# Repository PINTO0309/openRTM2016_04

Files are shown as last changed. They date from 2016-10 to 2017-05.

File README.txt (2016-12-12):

README

甲南大学知能情報学部
2016/10/31
2016/12/10 アップデートにあわせて改訂
2016/12/12 作例：ライントレーサーのアップデート，利用マニュアルの改訂，Zumo通信プロトコル解説マニュアルの追加

このフォルダには，RTミドルウェアコンテスト2016に参加している「ZumoとRaspberry Piを用いた教育用ロボット環境」の作品データが保存されています．作品は以下のフォルダ，ファイルから構成されています．

(1) Zumo ロボット用 RT Component群
　　(a) 基本コンポーネント
    (b) ゲームパッド入力コンポーネント
    (c) ゲームパッド速度指令コンポーネント
    (d) Zumo-Raspberry Pi間通信テスト用コンポーネント群
    (e) 作例：ライントレーサー
(2) Zumo ロボット内制御プログラム (Micro USBポート接続版(通常はこちらを使用), GPIO接続版(Raspberry Pi A+用)）
(3) Zumo基板上にRaspberry Piを搭載するためのCADデータ
(4) Zumoロボットの利用マニュアル

(2)のロボット内制御プログラムは，Zumoロボット基板上のMicro USBポート経由でのシリアル通信（通常はこちらを使用）と，Zumoロボット基板上のGPIOシリアル通信を利用の場合（Raspberry Pi A+を想定）の2種類があります．通常はMicro USBポート経由のプログラムを用いますが，ご使用の環境に応じて，プログラムを使い分ける必要があります．

フォルダ，ファイルの一覧は以下のとおりです．

- README.txt		README
- ZumoComponents	Pololu Zumo 32U4 RTコンポーネント群
			- 基本コンポーネント
			- ゲームパッド入力
			- ゲームパッド速度指令コンポーネント
 +- IO_test		Zumo - Rasperry Pi 間の通信テスト用コンポーネント群
 +- sample		作例：ライントレーサー
- Zumo-USB		Zumoロボット内制御プログラム（Micro USBポート経由シリアル通信版，通常はこちらを使用）
- Zumo-GPIO		Zumoロボット内制御プログラム (GPIOシリアル通信版）
- CADData		ZumoロボットへのRaspberry Pi マイクロコントローラ搭載用CADデータ
- Manual.pdf		利用マニュアル
- ZumoCommunicationProtocol_Manual.pdf  Zumo通信プロトコル解説マニュアルの追加
これらの，フォルダ，ファイルを利用して，Zumoロボットのアプリケーションソフトウェアの開発が行えます．

以上

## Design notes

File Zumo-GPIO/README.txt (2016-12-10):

README

甲南大学知能情報学部
2016/10/31
2016/12/10  改訂 ソフトウェアの使用に関する注意（シリアル通信を行うための主な手段の変更による）

このフォルダには，RTミドルウェアコンテスト2016に参加している「ZumoとRaspberry Piを用いた教育用ロボット環境」のZumo ロボット内制御プログラム (GPIOシリアル通信版）が保存されています．作品は以下のファイルから構成されています．

(1) Zumo ロボット用 Arduino統合環境設定ファイル 
(2) ロボット制御用C++ソース，ヘッダファイル群

（注）
このロボット内制御プログラムは，Zumoロボット基板上のGPIOシリアル通信を利用の場合（Raspberry Pi A+を想定）用です．
Zumoロボット内制御プログラムには，Zumoロボット基板上のGPIOシリアル通信を利用の場合（Raspberry Pi A+を想定），Micro USBポート経由でのシリアル通信（通常はこちらを使用）の2種類があります．ご使用の環境に応じて，プログラムを使い分ける必要があります．

フォルダ，ファイルの一覧は以下のとおりです．

- README.txt		README
- Zumo-rasp.ino		Pololu Zumo 32U4用プログラム Arduino統合環境 設定ファイル
			（Zumoロボット基板上のGPIOシリアル通信を利用）
- *.cpp, *.h		モータ，ボタン，シリアル通信用プログラム

これらの，フォルダ，ファイルを利用して，Zumoロボットのアプリケーションソフトウェアの開発が行えます．Zumoロボットそのもの機能の追加には，このプログラム群を修正，改良して，開発を行います．

以上

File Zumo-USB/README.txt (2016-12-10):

README

甲南大学知能情報学部
2016/10/31
2016/12/10  改訂 ソフトウェアの使用に関する注意（シリアル通信を行うための主な手段の変更による）

このフォルダには，RTミドルウェアコンテスト2016に参加している「ZumoとRaspberry Piを用いた教育用ロボット環境」のZumo ロボット内制御プログラム （Micro USBポート経由でのシリアル通信版，通常はこちらを使用）が保存されています．作品は以下のファイルから構成されています．

(1) Zumo ロボット用 Arduino統合環境設定ファイル 
(2) ロボット制御用C++ソース，ヘッダファイル群

（注）
このロボット内制御プログラムは，Micro USBポート経由でのシリアル通信用です．通常はこちらのファイル群を使用します．
Zumoロボット内制御プログラムには，Micro USBポート経由でのシリアル通信（通常はこちらを使用），Zumoロボット基板上のGPIOシリアル通信を利用の場合（Raspberry Pi A+を想定）の2種類があります．ご使用の環境に応じて，プログラムを使い分ける必要があります．

フォルダ，ファイルの一覧は以下のとおりです．

- README.txt		README
- Zumo-rasp.ino		Pololu Zumo 32U4用プログラム Arduino統合環境 設定ファイル
			（Zumoロボット基板上のGPIOシリアル通信を利用）
- *.cpp, *.h		モータ，ボタン，シリアル通信用プログラム

これらの，フォルダ，ファイルを利用して，Zumoロボットのアプリケーションソフトウェアの開発が行えます．Zumoロボットそのもの機能の追加には，このプログラム群を修正，改良して，開発を行います．

以上

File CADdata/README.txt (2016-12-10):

README

甲南大学知能情報学部
2016/10/28
2016/12/10 改訂 治具の変更，追加に伴う改訂

このフォルダには，Zumoの基板上にRaspberry Piシリーズを載せるための治具のCADデータおよび3Dプリンタ(Afinia H480)用データ（STL形式）が保存されています．治具は以下の3種類のパーツから構成されています．

(1) 治具A
(2) 治具B
(3) スペーサー

これらのパーツのCADデータはDesignSparkにて作成しました．そのデータを治具についてはSTL形式，スペーサーについてはUP3形式に変換してあります．これらのデータが以下のファイル名で保存されています．

- JigA-1.stl, JigA-2.stl, JigA-3.stl, JigA-4.stl        治具A（Raspberry Pi Bシリーズ用）の3Dプリンタ用データ(STL形式)
- JigB-1.stl, JigB-2.stl       				治具B (Raspberry Pi A+用）3Dプリンタ用データ(STL形式)
- six_spacers.UP3  スペーサー6個分の3Dプリンタ用データ

これらの治具を用いてRaspberry Piコントローラを固定する方法については，本プロジェクトのマニュアルを参照してください．

以上

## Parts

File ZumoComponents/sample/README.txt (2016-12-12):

README

甲南大学知能情報学部
2016/10/31 作成
2016/12/10 ライントレーサー用RTコンポーネント改良
2016/12/12 ライントレーサー用RTコンポーネント改良,スイッチ駆動によるライントレーサー実行環境の追加

このフォルダには，RTミドルウェアコンテスト2016に参加している「ZumoとRaspberry Piを用いた教育用ロボット環境」のPololu Zumoロボット用RTコンポーネント群の作例が保存されています．

このフォルダには，本ロボットを動作させる作例として以下のファイル，フォルダから構成されています．

(1) 作例：ライントレーサーRTコンポーネント

これらのコンポーネントはPythonで書かれており，Raspberry Pi，Windows などプラットフォームを問わず，実行できます．これらのデータは以下のファイル名で保存されています．

- LineTracer.py		ライントレーサー用RTコンポーネント
+ SwitchExecute		スイッチ駆動によるライントレーサー実行環境のディレクトリ

これらのRTコンポーネント群を用いてZumoロボットのサンプルを動かす方法については，本プロジェクトのマニュアルを参照してください．

以上

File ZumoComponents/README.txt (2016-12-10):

README

甲南大学知能情報学部
2016/10/31
2016/12/10 Zumo制御用RTコンポーネント，作例（ライントレーサー用RTコンポーネント）改良

このフォルダには，RTミドルウェアコンテスト2016に参加している「ZumoとRaspberry Piを用いた教育用ロボット環境」のPololu Zumoロボット用RTコンポーネントが保存されています．

このフォルダには，本ロボットを動作させる最小構成のコンポーネント群として以下のファイル，フォルダから構成されています．

(1) Zumo制御用RTコンポーネント
(2) 速度指令RTコンポーネント
(3) ジョイスティック入力コンポーネント
(4) Zumoロボット 制御I/Oテスト用コンポーネント群
(5) 作例：ライントレーサーRTコンポーネント

これらのコンポーネントはPythonで書かれており，Raspberry Pi，Windows などプラットフォームを問わず，実行できます．これらのデータは以下のファイル名で保存されています．

- Zumo.py		Pololu Zumo 制御用RTコンポーネント
- JoyVelRTC.py 		ジョイスティック用速度指令RTコンポーネント
- JoystickRTC.py	ジョイスティック入力RTコンポーネント
- IO_test		Zumoロボット 制御I/Oテスト用コンポーネント群
- LineTracer.py		ライントレーサー用RTコンポーネント（作例）
これらのRTコンポーネント群を用いてZumoロボットのサンプルを動かす方法については，本プロジェクトのマニュアルを参照してください．

以上

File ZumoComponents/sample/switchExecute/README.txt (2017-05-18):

2017/5/16(月曜日)

このスクリプト群はRaspberry Piの起動時にスイッチで各コンポーネントを起動できるようにするためのプログラムです。
このスクリプト群を使うにあたり、各プログラムの配置場所に注意してください。

各プログラムの説明です。
・ComponentControl.py
スイッチの入力を感知すると、Zumo.py、LineTracer.pyなどのコンポーネントを立ち上げRTShellでコンポーネントの接続、コンフィグの変更、コンポーネントの実行停止を行います。場所は/home/pi/においてください。

・runZumo.sh
ComponentControl.pyを動かすためのシェルファイルです。場所は/etcにおいてください。

・rc.local
Raspberry Pi の/etc/に存在するファイルです。このスクリプトを置きかえることで起動時に自動でComponentControl.pyが起動し、スイッチを押すだけでコンポーネントが立ち上がりZumoが動き始めます。

なお、配置場所を変える際には適宜スクリプトファイルを書き換えてください。

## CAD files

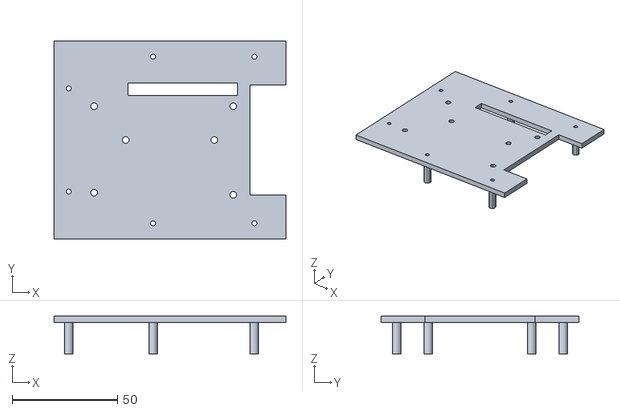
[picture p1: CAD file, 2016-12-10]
CADdata/JigA-4.stl
110.0 x 94.0 x 18.0

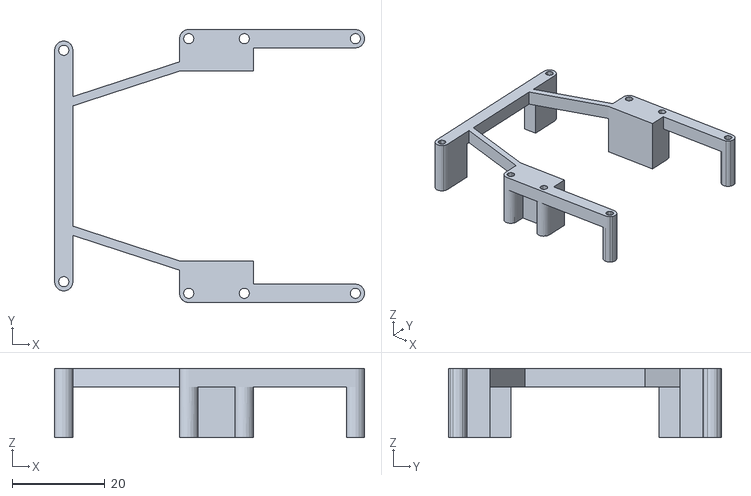
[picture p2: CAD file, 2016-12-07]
CADdata/JigA-1.stl
67.0 x 59.0 x 15.0

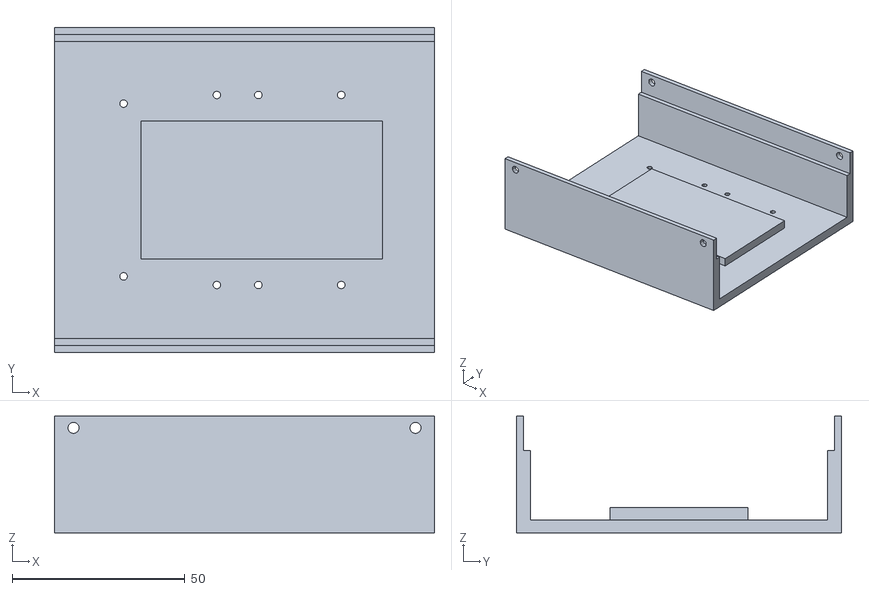
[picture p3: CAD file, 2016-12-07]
CADdata/JigA-2.stl
110.0 x 94.0 x 33.8

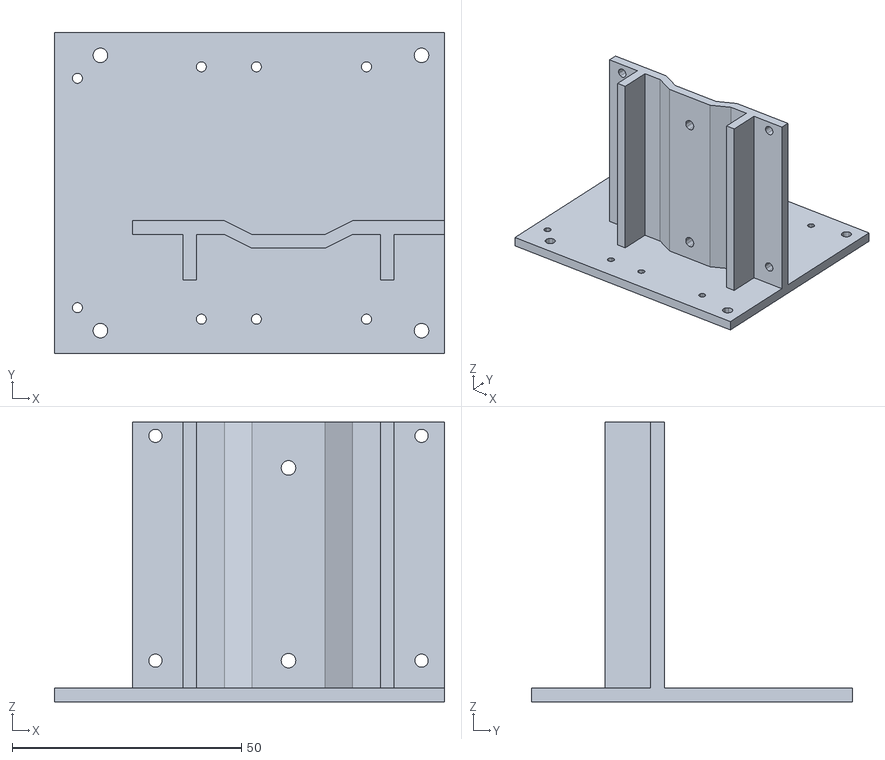
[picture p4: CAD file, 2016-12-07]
CADdata/JigB-2.stl
85.0 x 70.0 x 61.0

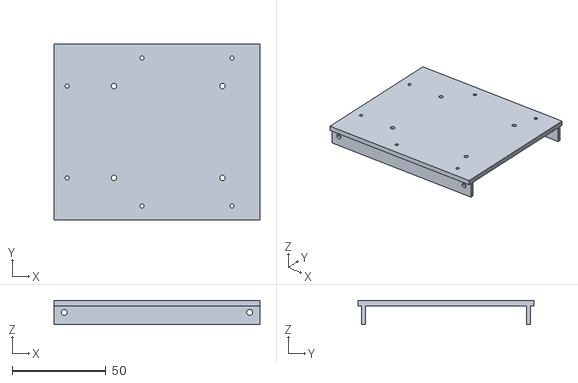
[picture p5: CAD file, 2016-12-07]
CADdata/JigA-3.stl
110.0 x 94.0 x 12.9

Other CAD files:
CADdata/JigB-1.stl

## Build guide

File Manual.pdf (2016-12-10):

1

# 「Zumo と Raspberry Pi を用いた教育用

# ロボット環境」利用マニュアル

2016 年 12 月 10 日第 2 版
甲南大学知能情報学部

2

目次

2.2.3. micro SD カードへのイメージファイルの書き込み (Raspberry Pi 2,

3

4

1. まえがき

小型台車ロボット Zumo 32U4 と Raspberry Pi を組み合わせた教育用ロボットを制御す るための RT コンポーネント群を開発しました．これらのコンポーネント群は Raspberry Pi 単体でも動作し，安価かつ小型で拡張性の高いシステムを提供します． このコンポーネント群は以下の特徴を持っています．
- ロボットに搭載されたマイクロコントローラ Raspberry Pi のみで，移動ロボットを制 御することができます．
- 最小構成で Raspberry Pi を搭載した卓上の移動ロボットシステムを構築できるため， RT ミドルウェアのソフトウェア資産を生かし，容易に拡張性の高いロボットシステム を作ることができます．
- コンポーネント群は OS のプラットフォームに依存しないため，柔軟性が高い教育用ロ ボットシステムを構築できます．
- Raspberry Pi を用いた移動ロボット構築例を作るための治具の CAD データ，3D プリ ンタ用データを公開しています．
- 標準的な移動ロボット制御コンポーネントに対応できるように，Raspberry Pi, Windows 側で動作する Zumo コンポーネントに対応する Zumo ロボット側の制御プロ グラムを公開しています．
- 本ロボットシステムの RT コンポーネントは，2015 年に応募した XML で動作する対 話ロボットシステムのロボットベース部を改良した，現行の小型漫才ロボット(こちら) の制御に用いられています．

5

2. Raspberry Pi の設定方法
2.1. 用意するもの
- Raspberry Pi 3 Model B
- micro SD カード（8 GB 以上）
- WiFi 子機（本資料では Buffalo WLI-UC-GNM2 を使用する）
- WiFi 付きの Raspberry Pi を使用する場合には不要
- USB ハブ
- USB ケーブル（A－micro B）
- PC
- 内蔵もしくは外付けの SD カードスロットが必要
- 本資料では Windows 7 機を使用する
- ディスプレイ（HDMI から信号を入力できるケーブルが必要）
- キーボード
- マウス
2.2. 作業手順

以下の OS のインストールは，Raspberry Pi 2, Raspberry Pi A+の場合について説明し ている．Raspberry Pi 3 では，2016 年 12 月標準のインストールバージョン (jessie)を使用 する．

2.2.1. OS のイメージファイルのダウンロード

PC にて以下の URL にアクセスし， Raspbian wheezy（Raspberry Pi 用 OS）のイメー ジファイル（約 1 GB）をダウンロードする¹．そして，Windows のコンテキストメニュー の「すべて展開…」その ZIP ファイルを展開する²．

http://ftp.jaist.ac.jp/pub/raspberrypi/raspbian/images/raspbian-2015-05-07/ (http://ftp.jaist.ac.jp/pub/raspberrypi/raspbian/images/raspbian-2015-05-07/)2015-05-05-raspbian-wheezy.zip (http://ftp.jaist.ac.jp/pub/raspberrypi/raspbian/images/raspbian-2015-05-07/2015-05-05-raspbian-wheezy.zip)

2.2.2. Win32 Disk Imager のインストール
PC にて以下の URL などから Win32 Disk Imager のインストーラー（本資料執筆時は

Win32DiskImager-0.9.5-install.exe）を入手し，インストールする．

https://osdn.net/projects/sfnet_win32diskimager/

1 Raspbian の最新版は jessie であるが，Raspberry Pi 2 では wheezy を使用している． Raspberry Pi 3 では jessie を用いてシステムを構築している．
2 インストールされているソフトウェアによってはメニューが異なる場合がある．

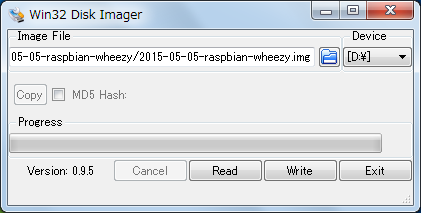
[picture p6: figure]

6

2.2.3. micro SD カードへのイメージファイルの書き込み (Raspberry Pi 2, Raspberry Pi

A+の場合)
まず，SD カードを SD カードスロットにセットする．PC に SD カードスロットがない 場合には，外付け SD カードスロットを用いる．次に，Win32 Disk Imager を起動し，イ

メージファイルとして 2015-05-05-raspbian-wheezy.img を指定する（図 1）．そして，Write ボタンをクリックし，SD カードへの書き込みを行う．Write Successful のダイアログ（図

2）が表示されたら，Win32 Disk Imager を終了する．

図 1：Win32 Disk Imager

図 2：書き込み終了を示すダイアログ

2.2.4. Raspberry Pi の起動と RTM のインストール

2.2.3 にて作成した micro SD カードを Raspberry Pi の micro SD カードスロットに挿入 する．Raspberry Pi にディスプレイ，キーボード，マウス，WiFi 子機（必要な場合）を接 続した上で，USB ケーブルから電源を投入する．初回起動時には，必要に応じて言語やキ ーボードに関する設定を行う．
OS が起動し，コマンドプロンプトが表示されたら，startx コマンドにより GUI 環境を 起動する．次に，WiFi の設定を行う．ネットワークに接続したら，以下の Web ページに従 って，Raspberry Pi 用の RTM をインストールする．

http://openrtm.org/openrtm/ja/content/raspberrypi_openrtm_installation

7

ただし，2016 年 10 月 18 日現在，上記のページには誤りがある．/etc/apt/sources.list の 編集後，apt-get により関連ファイルのインストールを行う部分で，python-omniorb-omg と omniidl-python もインストールする必要がある．以下では，sudo を使って実行する例を 示している．赤字の部分が上記のページに記載されていない部分である．

$ sudo apt-get update

$ sudo apt-get -y --force-yes install gcc g++ make uuid-dev

$ sudo apt-get -y --force-yes install libomniorb4-dev omniidl omniorb-nameserver

$ sudo apt-get -y --force-yes install openrtm-aist openrtm-aist-dev openrtm-aist-example

$ sudo apt-get -y --force-yes install openrtm-aist-python openrtm-aist-python-example

$ sudo apt-get install python-omniorb-omg omniidl-python

以上で Raspberry Pi の設定は完了である．

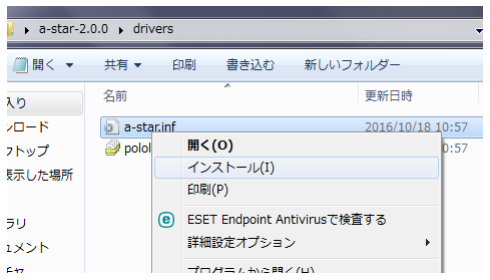
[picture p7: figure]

8

3. Zumo 32U4 Robot の設定
3.1. 用意するもの
- Zumo 32U4 Robot
- USB ケーブル（A－micro B）
- PC
3.2. 作業手順
3.2.1. PC へ Arduino Software のインストール
PC にて以下の URL にアクセスし，最新の Arduino Software をダウンロードしインス トールする．執筆時点のバージョンは 1.6.12 である．

https://www.arduino.cc/en/Main/Software

3.2.2. PC へ Zumo 用デバイスドライバのインストール
PC にて以下の URL にアクセスし，a-star-2.0.0.zip をダウンロードし展開する．次に, 展開したフォルダーの drivers 内にある a-star.inf をコンテキストメニューからインストー ルする（図 3）.

https://www.pololu.com/file/download/a-star-2.0.0.zip?file_id=0J743

図 3：ドライバーのインストール

さらに, a-star-2.0.0¥add-on フォルダー内の polou フォルダー全体を C:¥Program

Files (x86) ¥Arduino¥hardware の中にコピーする（図 ）．

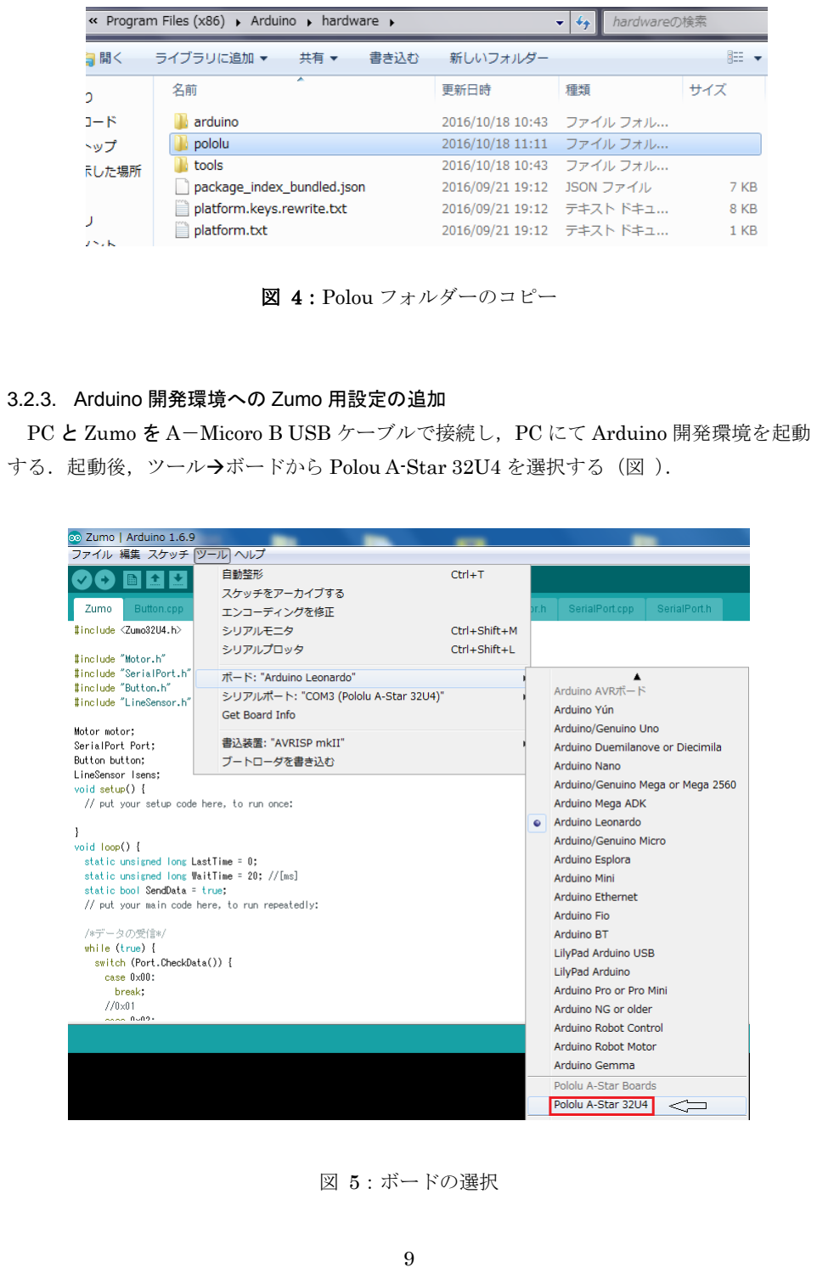
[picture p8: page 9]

9

図 4：Polou フォルダーのコピー

3.2.3. Arduino 開発環境への Zumo 用設定の追加

PC と Zumo を A－Micoro B USB ケーブルで接続し，PC にて Arduino 開発環境を起動 する．起動後，ツール→ボードから Polou A-Star 32U4 を選択する（図 ）．

図 5：ボードの選択

10

最後に，デバイスマネージャーのポート（COM と LPT）に Pololu A-star 32U4 が表示 されていることを確認する（図 ）．

図 6：COM ポートの確認

以上で Zumo 32U4 Robot の設定は完了である．

参考：https://www.pololu.com/docs/0J61/6.1

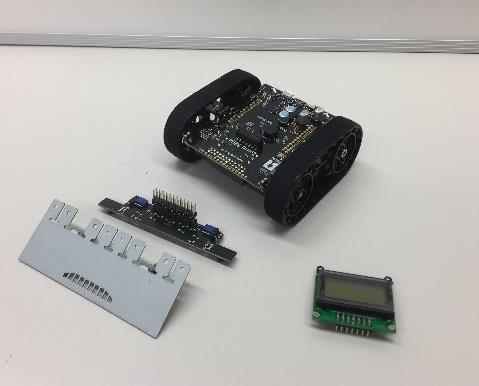
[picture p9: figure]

11

4. Zumo と Raspberry Pi の組み立て手順
4.1. 用意するもの
- Raspberry Pi 3 Model B
- Zumo 32U4 Robot
- | 3D プリンタで出力した治具 A-1，A-2，A-3，A-4 | 各 1 個（CAD データおよ
び 3D プリンタ用データが本プロジェクトのホームページにて公開されている）
- | M3×15 ネジ | 8 本
- | M2.6×15 ネジ | 4 本
- | M2×25 ネジ | 14 本
- | M3 ナット | 8 個
- | M2.6 ナット | 4 個
- | M2 ナット | 14 個（うち 4 個は Zumo に付いているものを使用する）
- | スペーサー（M2.6 ネジ用，高さ 3 mm） | 4 個（3D プリンタ用データが本プロ
ジェクトのホームページにて公開されている）
4.2. 作業手順
4.2.1. Zumo 側の準備
Zumo についているブレード，赤外線センサアレイ，液晶ディスプレイを取り外す．

図 7：Zumo のブレード，赤外線センサアレイ，液晶ディスプレイを取り外した状態

4.2.2. RaspberryPi ユニットの取り付け

治具 A-1，A-2 を Zumo の基板上にネジで固定する．図 8 左のように先に治具 A-1 を基板 に載せ，その上に図 8 右のように治具 A-2 を載せてネジで固定する．ブレードが固定され ていた 2 か所（図 9）では冶具から Zumo に向かってネジを通し，それ以外の 6 か所では Zumo の電池ボックスの内側 sudo apt-get -y --force-yes install openrtm-aist openrtm-aist-dev

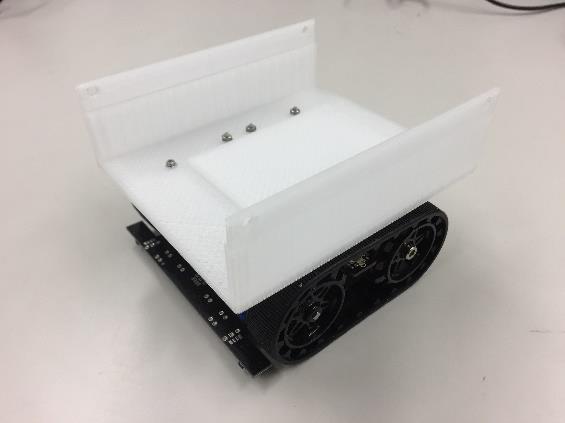
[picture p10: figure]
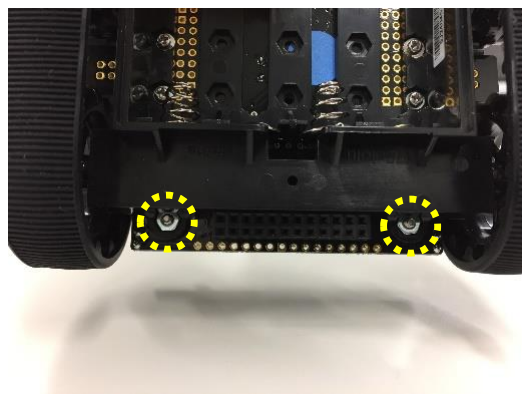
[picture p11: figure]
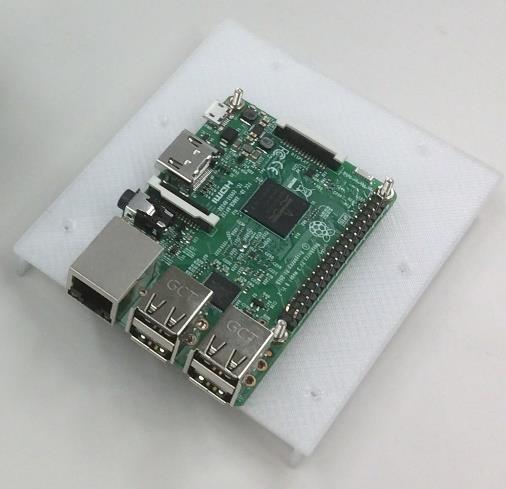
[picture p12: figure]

12

openrtm-aist-example から冶具に向かってネジを通す．

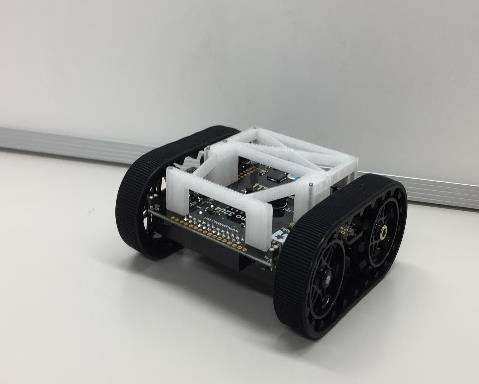
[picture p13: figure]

図 8：治具 A-1（左図），治具 A-2（右図）の取り付け

図 9：治具側からネジを挿入する部分

ネジの取り付け完了後，赤外線センサアレイを元の位置のピンコネクタに挿す．

冶具 A-3 に Raspberry Pi を取り付ける．
この際，冶具 A-3 と Raspberry Pi の間にスペーサーを取り付ける． 冶具 A-4 にユニバーサル基板用のネジを天板の裏側から取り付ける．

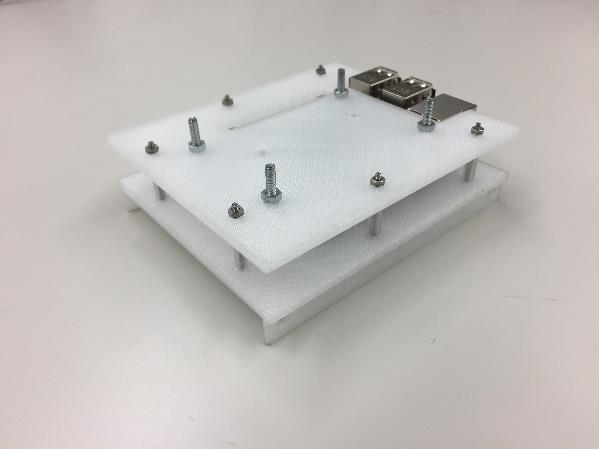
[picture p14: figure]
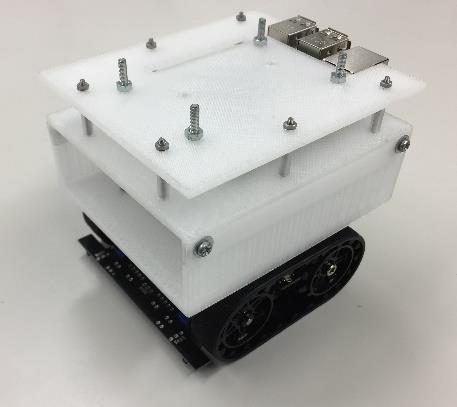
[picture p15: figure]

13

図 10：冶具 A-3 へ Raspberry Pi を取り付けた様子

冶具 A-3 に冶具 A-4 を取り付ける．
図 11 のように冶具 A-3 から冶具 A-4 に向かってネジを通す．

図 11：冶具 A-3 に冶具 A-4 を取り付けた様子

冶具 A-2 に冶具 A-3 を取り付ける．

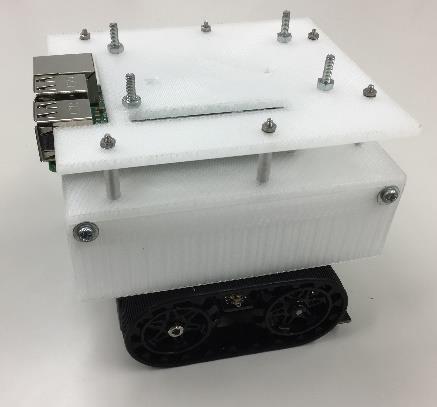
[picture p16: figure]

図 12：冶具 A-2 に冶具 A-3 を取り付けた様子

以上で組み立ては完了である．

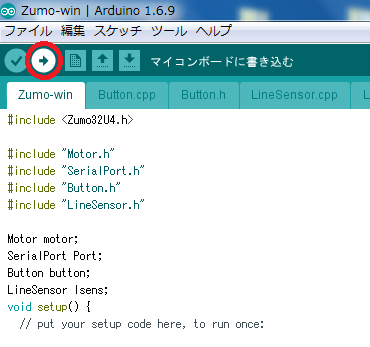
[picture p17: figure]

14

5. Zumo 用プログラムの書き込み
5.1. 用意するもの
- Zumo 32U4 Robot
- USB ケーブル（A－micro B）
- PC（3 節の設定を済ませたもの）
- プログラム（本プロジェクトの web ページよりダウンロードする）
- Zumo 後方の USB ポートを経由して Zumo を制御する場合：Zumo-USB フォル ダー（通常はこちらを使用する）
- Raspberry Pi Model A+から GPIO シリアル通信を用いて Zumo を制御する場合 （付録を参照）：Zumo-GPIO フォルダー
5.2. 作業手順
まず，PC と Zumo を USB ケーブルで接続する．次に，Zumo にプログラムを書き込む． 以下，Zumo 後方の USB ポートを経由して Zumo を制御する場合を例に説明する．PC に

て Zumo-USB.ino をダブルクリックして，Arduino software を起動する（Raspberry Pi Model A+などで GPIO シリアル通信によって制御する場合には Zumo-GPIO.ino をダブル クリックする）．そして，メニューバーの直下にある矢印アイコンをクリックすることによ って，プログラムが検証，コンパイルされ，Zumo に書き込まれる（図 33）．

図 33：Zumo へのプログラムの書き込み

以上で Zumo 用プログラムの書き込みは完了である.

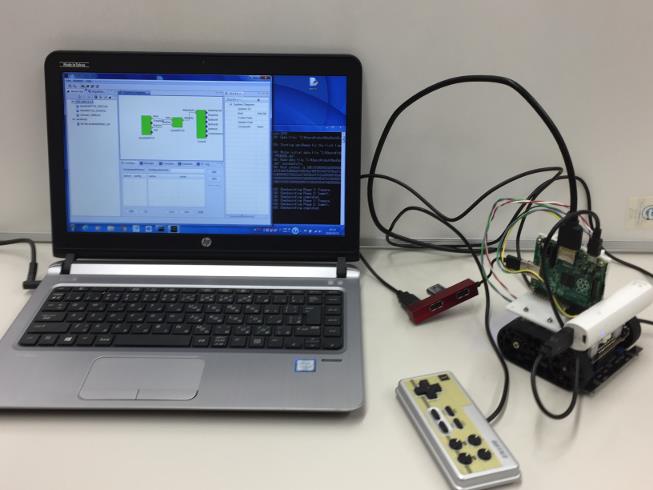
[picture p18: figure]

15

6. 作例の動かし方

本節ではゲームパッドを用いて Zumo 32U4 を制御する方法を説明する．Raspberry Pi 上で RTShell を動かすことによって一連の処理を Raspberry Pi のみで実行することも可 能だが，ここでは，PC 上の RT System Editor でコンポーネントの接続や実行を行う方法 を説明する．

図 44：ゲームパッドによる Zumo の制御 (Raspberry Pi A+での構成)

6.1. 用意するもの
- Zumo 32U4 に Raspberry Pi 3 Model B を接続したシステム（5 節までで設定したも の）³
- Raspberry Pi 3 Model B に接続するディスプレイ，キーボード，マウス
- ゲームパッド（本資料では Buffalo BGCFC801 を使用）
- PC（上記の Raspberry Pi と同じネットワークに接続されているもの）
6.2. 作業手順
6.2.1. システムの起動

Zumo および Raspberry Pi 3 Model B を起動する．Raspberry Pi 3 Model B にはディス プレイ，キーボード，マウス，ゲームパッドを接続しておく．

3 2016 年 10 月 31 日現在，Raspberry Pi A+はこの処理に対して非力であることが分かっ ている．
2016 年 12 月 10 日現在では，Raspberry Pi 3 で Zumo 後方の USB ポートを経由した シリアル通信を用いることを標準とする．

16

6.2.2. Zumo へのプログラムの書き込み

5 節の記述に従って，Zumo_USB.ino を Zumo に書き込む．

6.2.3. Name サーバーの起動
2.2.4 節での omniorb-nameserver のインストール時に，システム起動時に自動的に omniORB のネームサービスが起動するようになっている⁴．しかし，起動がうまくいかな い場合には rtm-naming コマンドによりネームサーバを再起動する．
6.2.4. Raspberry Pi の IP アドレスの取得
ifconfig を使うなどして Raspberry Pi の IP アドレスを取得してメモしておく．
6.2.5. RT コンポーネントのダウンロード
本プロジェクトのホームページから以下の 3 つのコンポーネントをダウンロードする．
(1) Zumo.py
(2) JoyVelRTC.py
(3) JoystickRTC.py
6.2.6. RT コンポーネントの起動
Raspberry Pi にて上記 3 つのコンポーネントを起動する．具体的には，Raspberry Pi の 端末上にて以下のコマンドを実行する．

$ cd (上記ファイルのあるフォルダー)

$ sudo python Zumo.py&
$ sudo python JoyVelRTC.py&
$ sudo python JoystickRTC.py&
6.2.7. コンポーネントの接続・実行

PC で RT System Editor を起動し，「name server の追加」で Raspberry Pi の IP アド レスを追加する．すると，上記 3 つのプロセスが表示されるので，それらを図 のように配 置，接続する．
次に，Zumo コンポーネントのコンフィギュレーションの Port の値を /dev/ttyACM0 に 変更する（図 6）．これは接続するシリアルポートの設定である． 以上の設定が済んだら，アクティベートを行う．これによって，ゲームパッドで Zumo を 制御することができるようになる．

4 参考：http://openrtm.org/openrtm/ja/content/raspberrypi_openrtm_installation

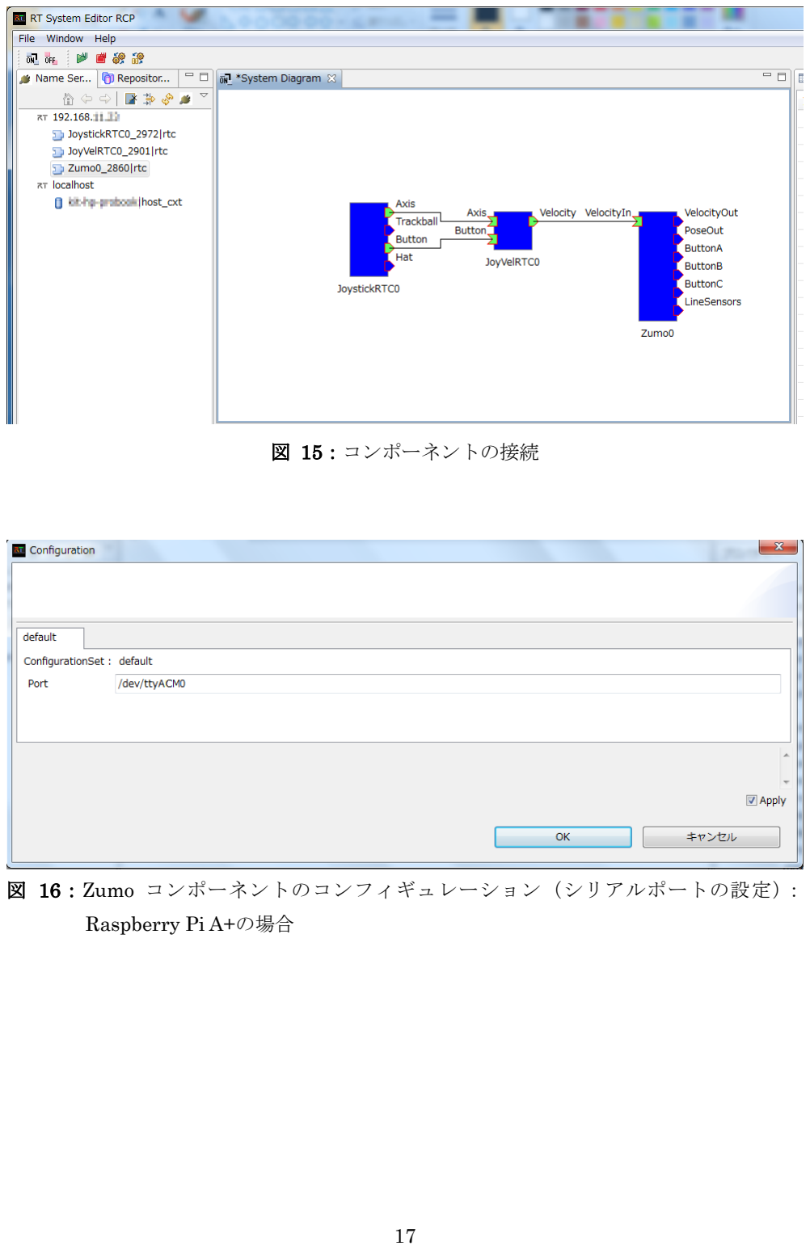
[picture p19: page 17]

17

図 15：コンポーネントの接続

図 16：Zumo コンポーネントのコンフィギュレーション（シリアルポートの設定）：

Raspberry Pi A+の場合

18

7. コンポーネントの説明

概要
速度と角速度の入力に応じて Zumo を移動させる．速度と角速度，オドメトリ，Zumo 本 体のボタンの On/Off，赤外線センサアレイのデータを出力する．

データポート

名称 | フローポート | データ型 | 説明
VelocityIn | InPort | RTC.TimedVelocity2D | 速度情報を入力する．
VelocityOut | OutPort | RTC.TimedVelocity2D | 速度情報を出力する．
PoseOut | OutPort | RTC.TimedPose2D | 起動直後からのオドメト リを出力する．
ButtonA | OutPort | RTC.TimedBoolean | ButtonA の On/Off を出力 する．
ButtonB | OutPort | RTC.TimedBoolean | ButtonB の On/Off を出力 する．
ButtonC | OutPort | RTC.TimedBoolean | ButtonC の On/Off を出力 する．
LineSensors | OutPort | RTC.TimedULongSeq | ラインセンサデータを出 力する．

### Zumo

19

概要
ジョイスティックから入力されたボタン情報を速度情報に変換し出力する．

データポート

名称 | フローポート | データ型 | 説明
Axis | InPort | RTC.TimedDoubleSeq | ジョイスティックへの入 力情報を入力する．
Button | InPort | RTC.TimedBooleanSeq | ジョイスティックへのボ タンの入力情報を入力す る．
Velocity | OutPort | RTC.TimedVelocity2D | 速度情報を出力する．

### JoyVelRTC

20

概要
ジョイスティックやゲームパッドへの入力を出力する．

データポート

名称 | フローポート | データ型 | 説明
Axis | OutPort | RTC.TimedDoubleSeq | 座標軸を出力する．
Trackball | OutPort | RTC.TimedDoubleSeq | トラックボールの情報を 出力する．
Button | OutPort | RTC.TimedBooleanSeq | ボタンの情報を出力す る．
Hat | OutPort | RTC.TimedShortSeq | ハットスイッチの情報を 出力する．

### JoystickRTC

21

概要
Zumo の赤外線センサアレイからのデータをモニタするためのコンポーネントである．デ ータの型は符号無し long 型の配列で，その値が端末に表示される．

データポート

名称 | フローポート | データ型 | 説明
In | InPort | RTC.TimedULongSeq | Zumo から出力されるデ ータを端末に出力する．

### ULongSeqInPort

22

8. 付録：Raspberry Pi A+を用いたシステム構築
8.1. はじめに

Raspberry Pi A+では，USB ポートが少なく，Zumo ロボットとは GPIO 接続を用いて， シリアル通信を行う必要がある．そのため，電圧変換ボードの取り付けを行う．また，Zumo 側から見た通信経路が異なるため，Zumo 用プログラムについても，GPIO 経由での通信プ ログラム群を使用する．

8.2. 用意するもの
- Raspberry Pi A+
- Zumo 32U4 Robot
- 2 電源 8 ビット幅双方向ロジックレベル変換モジュール（秋月電気通商販売）1 個
- ケーブル（見分けのつくように別々の色を使うことが望ましい）
- ユニバーサル基板（46 mm × 35 mm）１枚
- | ケーブル A，B | 各 1 本
- ピンヘッダ 2.54 mm 間隔 1 列×4 ピン L 型 2 個
- QI コネクタ ハウジング 1×4 3 個
- QI コネクタ ハウジング 2×5 1 個
- | QI コネクタ用ピンメス | 16 個
- | M3×15 ネジ | 2 本
- | M2.6×15 ネジ | 4 本
- | M2×25 ネジ | 8 本
- | M3 ナット | 2 個
- | M2.6 ナット | 4 個
- | M2 ナット | 8 個（うち 4 個は Zumo に付いているものを使用する）
- | スペーサー（M2.6 ネジ用，高さ 3 mm） | 6 個（3D プリンタ用データが本プロ
ジェクトのホームページにて公開されている）
- 3D プリンタで出力した治具 B-1，B-2 各 1 個（CAD データおよび 3D プリンタ用デ ータが本プロジェクトのホームページにて公開されている）
8.3. 電圧変換モジュールの作成
電圧変換モジュールの回路図および作成例を図 17，図 18 に示す．この例では，ピンヘ ッダとロジックレベル変換モジュールをユニバーサル基板の表裏になるように取り付けて いる．

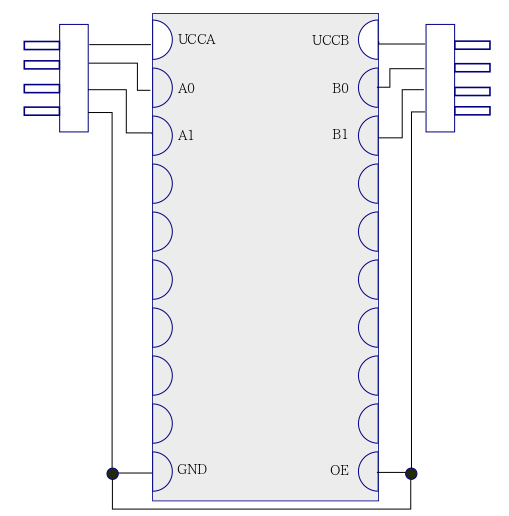
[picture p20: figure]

23

図 17：電圧変換モジュールの回路図

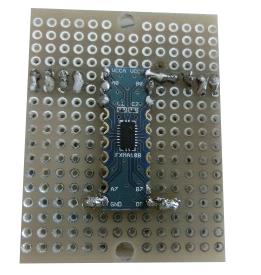
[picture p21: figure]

図 18：電圧変換モジュールの作成例（表裏）

8.4. 冶具のノイズ対策処理
治具 B-2 の 2 面（図 に示す二箇所）にノイズ対策のアルミ箔テープを貼る．

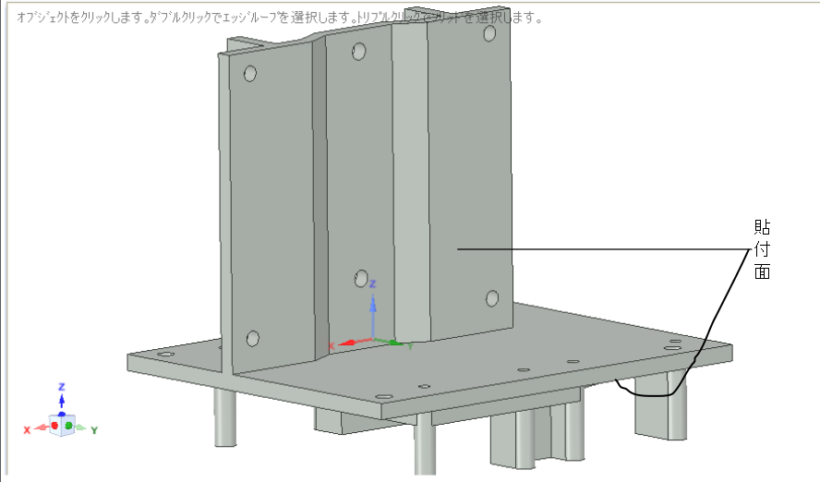
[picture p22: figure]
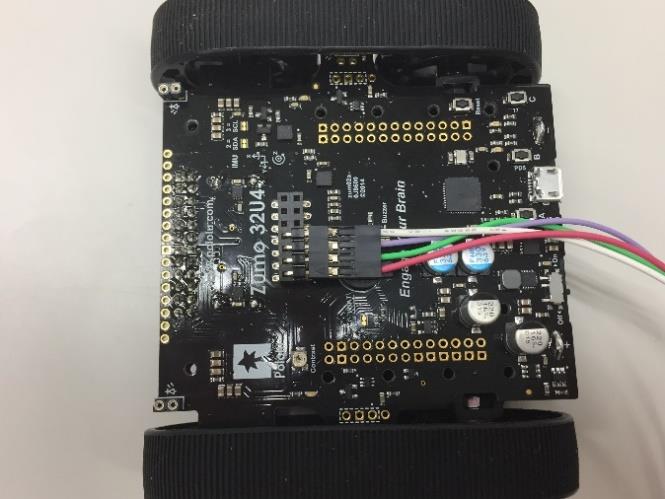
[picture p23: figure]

24

図 19：アルミ箔テープによりノイズ対策を施した冶具 B-2

8.5. 治具の取り付け
Zumo の液晶ディスプレイが接続されていたピンコネクタにピンヘッダ 2.54 mm 間隔 1 列×4 ピン L 型を挿し，ケーブル A を接続する（図 左）．この部分の回路図を図 右に示 す．

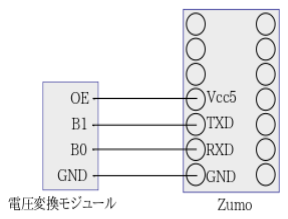
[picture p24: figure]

図 20：Zumo へのケーブル接続

次に，治具 B-1，B-2 を Zumo の基板上にネジで固定する．図 左のように先に治具 B-1 を基板に載せ，その上に図 右のように治具 B-2 を載せてネジで固定する．ブレードが固 定されていた 2 か所（図 ）では冶具から Zumo に向かってネジを通し，それ以外の 6 か 所では Zumo の電池ボックスの内側から冶具に向かってネジを通す．

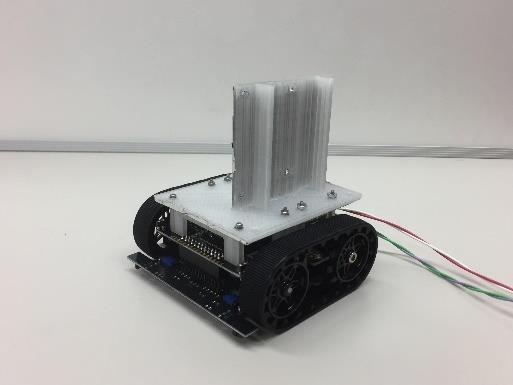
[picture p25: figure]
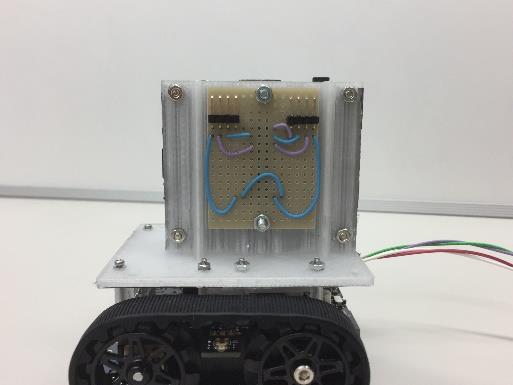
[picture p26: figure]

25

図 21：治具 B-1（左図），治具 B-2（右図）の取り付け

図 22：治具側からネジを挿入する部分

ネジの取り付け完了後，赤外線センサアレイを元の位置のピンコネクタに挿す．

8.6. 電圧変換モジュールの取り付け
電圧変換モジュールを治具 B-2 のアルミ箔テープを貼っていない面に取り付ける（エラ ー! 参照元が見つかりません。）．電圧変換モジュールの端子を取り付けた面が外側になる ようにネジで固定する．

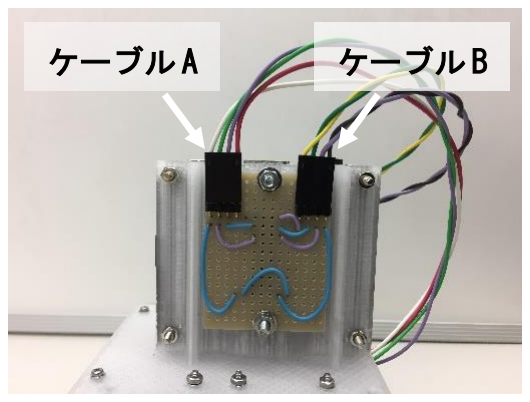
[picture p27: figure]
ケーブル A; ケーブル B

26

図 23：電圧変換モジュールを冶具 B-2 に取り付けた様子

8.7. Raspberry Pi の取り付け
治具 B-2 のアルミ箔テープを貼った面に Raspberry Pi A+を取り付ける（図 ）． Raspberry Pi と台座の間に必ずスペーサーを挟みネジで固定する．

図 24：冶具 B-2 へ Raspberry Pi を取り付けた様子

8.8. ケーブルの接続
まず，電源変換モジュールの左側のコネクタにケーブル A（Zumo に繋がっている）を接 続する．次に，電源変換モジュールの右側のコネクタにケーブル B を接続し，ケーブル B のもう一方を Raspberry Pi A+のピンヘッダに接続する．エラー! 参照元が見つかりません。 に接続した様子を示す．エラー! 参照元が見つかりません。は電圧変換モジュールと Zumo および Raspberry Pi A+との接続関係を図解したものである．

図 25：Zumo と Raspberry Pi A+の接続

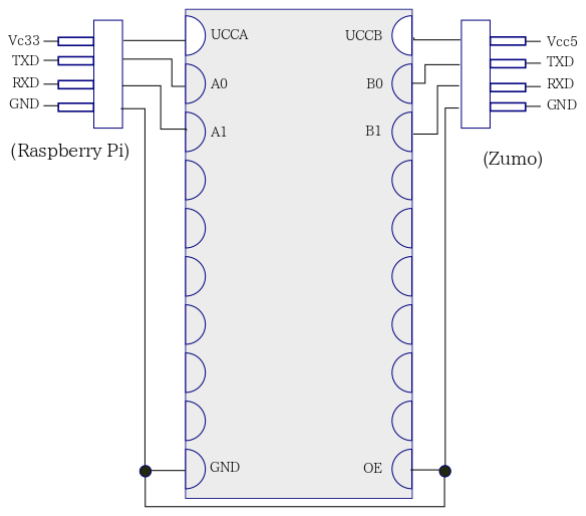
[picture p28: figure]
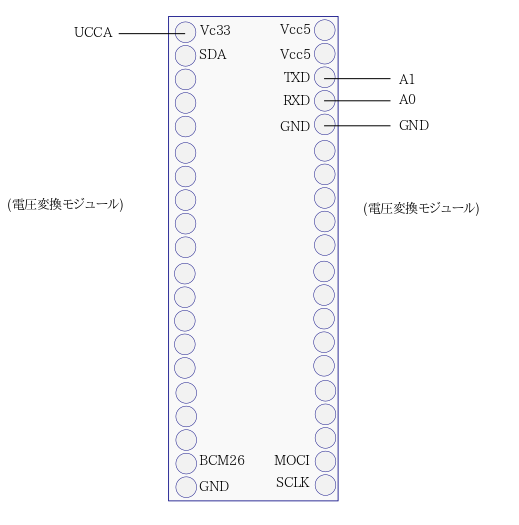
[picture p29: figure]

27

(a) 電圧変換モジュール
(b) Raspberry Pi A+

図 26：電圧変換モジュールと Zumo および Raspberry Pi A+との接続

以上で組み立ては完了である．

28

8.9. シリアル通信の設定
Raspberry Pi でシリアル通信を可能にするために設定を行う⁵．まず，Raspberry Pi にロ グインする．そして，コマンドプロンプトが表示されたら，startx コマンドにより GUI 環 境にする．次に，端末を起動し，以下の作業を行う．
(1) /boot/cmlline.txt のバックアップ

$ sudo cp /boot/cmdline.txt /boot/cmdline_backup.txt

(2) /boot/cmlline.txt の編集
以下のコマンドは nano というエディターの使用を想定しているが，好みに応じて vi を使用してもよいし，gedit をインストールして使用してもよい．

$ sudo nano /boot/cmdline.txt

変更前：

dwc_otg.lpm_enable=0 | console=ttyAMA0,115200 | kgdboc=ttyAMA0,115200
console=tty1 root=/dev/mmcblk0p2 rootfstype=ext4 rootwait
変更後：

dwc_otg.lpm_enable=0 rpitestmode=1 console=tty1 root=/dev/mmcblk0p2 rootfstype=ext4 rootwait

(3) OS の再起動
(4) /etc/inittab のバックアップ

$ sudo cp /etc/inittab /etc/inittab_backup.txt

(5) /etc/inittab の編集

$ sudo nano /etc/inittab

変更前：

T0:23:respawn:/sbin/getty -L ttyAMA0 115200 vt100 変更後：

# T0:23:respawn:/sbin/getty -L ttyAMA0 115200 vt100

5 参考：http://nanicananica.blog.fc2.com/blog-entry-14.html

29

(6) Raspberry Pi のシャットダウン

以上で Raspberry Pi の設定は完了である．

9. 更新情報
- 2016 年 10 月 31 日 初版
- 2016 年 12 月 10 日 Raspberry Pi 3 を標準とするシステム構成に改訂

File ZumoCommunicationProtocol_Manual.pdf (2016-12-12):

Zumo－上位コンピュータ間通信プロトコル

1. 概要

本文書では，Zumo と上位コンピュータ(Zumo.py)との通信手順について説明する．通常は， Zumo 内のプログラム（データ受信用関数 SerialPort::CheckData およびデータ送信用関数 SerialPort::Send），上位コンピュータでのプログラム（データ受信用関数 Receive，データ送 信用関数 Send）を使用する．これらの関数はこのプロトコルに沿って設計されている．Zumo に他のセンサを取り付けたり，インタフェースを追加して使用したりする場合には，このプ ロトコルにしたがって解釈部を追加することで機能を拡張できる．

2. 送受信データ形式

Zumo と上位コンピュータ間での通信にはシリアル通信を用いている．送受信データは以 下のように，標準で 4 Byte 分のデータを送信するときは 6 Byte で１組となる．送受信にお いては，データの誤りやパケット損失を考慮して，CRC およびデータ量を確認することで， 誤ったデータの送受信を防いでいる．

先頭バイト：上位 1 bit = 0，下位 7 bit=コマンド ID
2 バイト目～終端から 2 バイト目：上位 1 bit = 0，下位 7 bit = データ領域 終端バイト：上位 1 bit = 1, 下位 7 bit = データ領域（終端）＋CRC

送信データの各バイトの上位 1 bit は，データの終端かどうかを確認するために用いられ る．データの終端では，この上位 1 bit が 1 となり，それまでにバッファに蓄えられたデー タを解釈する．4 Byte 分のデータを送信するときは，CRC は 3 bit となる．今回のプログラム では，一度に 4 Byte のデータを送受信しているため，受信データが 6 Byte に満たない場合 は，データに欠損があることがわかるため，データは廃棄される．

3. 送受信コマンドの説明

Send(ID, Data) データを送信する．ID によって，第 2 引数 Data の型は異なる．本関数に よって送信されるコマンドの一覧を以下に示す．表中の Zumo は Zumo から，PC は上位コ ンピュータから各コマンドを送信可能であることを示す．

ID | データ型 | Zumo | PC | 送信内容
0x02 | float | ○ | ○ | 左クローラ速度（単位：ポイント/s） Zumo からは現在の速度，PC からは速度指令値を送る
0x03 | float | ○ | ○ | 右クローラ速度（単位：ポイント/s）

0x04 | bool | | ○ | 赤 LED（Zumo 上），True: 点灯，False: 消灯
0x05 | bool | | ○ | 緑 LED（Zumo 上），True: 点灯，False: 消灯
0x06 | bool | | ○ | 黄 LED（Zumo 上），True: 点灯，False: 消灯
0x08 | bool | ○ | | Zumo 上のタクトスイッチ（3 個），True: スイッチを押し た，False: スイッチから離れた，スイッチを押した瞬間， および，話した瞬間で True, False を出力する
0x09 | bool | ○
0x0a | bool | ○
0x10 | unsigned long | ○ | | Zumo 上のラインセンサの値 0x10～0x14 はラインセン サ 1～5 にそれぞれ対応する．値が取りうる範囲など， 条件については，Zumo ロボットのマニュアルを参照の こと．
0x11 | unsigned long | ○
0x12 | unsigned long | ○
0x13 | unsigned long | ○
0x14 | unsigned long | ○
0x74 | float | | ○ | P ゲイン（ロボットのモータの比例ゲイン：制御パラメータ （調整用）：初期値 0.1）
0x75 | float | | ○ | I ゲイン (ロボットのモータの積分ゲイン：制御パラメータ （調整用）：初期値 0.2）
0x76 | float | | ○ | D ゲイン（ロボットのモータの微分ゲイン：制御パラメータ （調整用）：初期値 0.05）
0x78 | bool | | ○ | データの送受信を行うかどうかの指令 True: 送受信を 行う（ロボットを動かす），False: 送受信を停止（ロボット を止める）
0x79 | unsigned long | | ○ | ロボットの制御周期（データの送受信間隔の設定（調整 用）：初期値 20 ms）

0x00: 何もしない（使用済）
0x01, 0x07, 0x0b から 0x0f, 0x15 から 0x73, 0x77, 0x7A から 0x7F：空き（未定義）

データ型で bool 型については，4 Byte の適切なデータに変換されてから送受信される． 受信時の解釈で，適切なデータ型に変換される．CPU のアーキテクチャによっては，整数 型のデータを送信する際，エンディアンに注意する必要がある．新たな機能の追加につい ては，Zumo.py（上位コンピュータ側），SerialPort.cpp, SerialPort.h を参照すること．

4. 更新情報
2016 年 12 月 12 日 初版

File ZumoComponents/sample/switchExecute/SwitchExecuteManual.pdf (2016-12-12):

スイッチ作成マニュアル
1. スイッチの作成
下記の図のようにスイッチのはんだ付けを行い、Raspberry Pi と接続する。

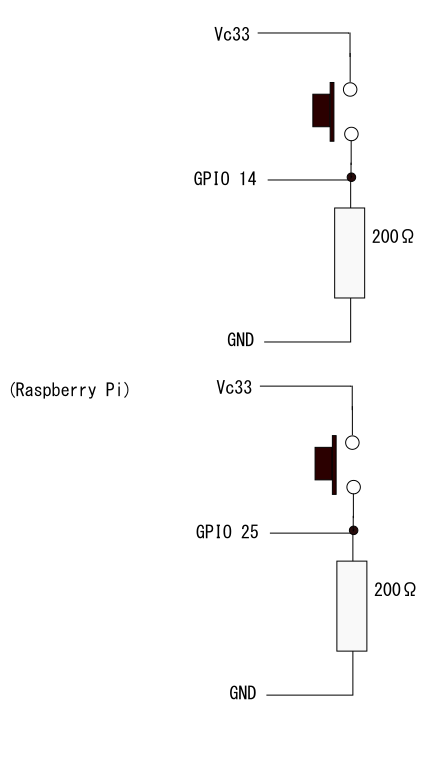
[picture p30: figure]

図 1 スイッチ

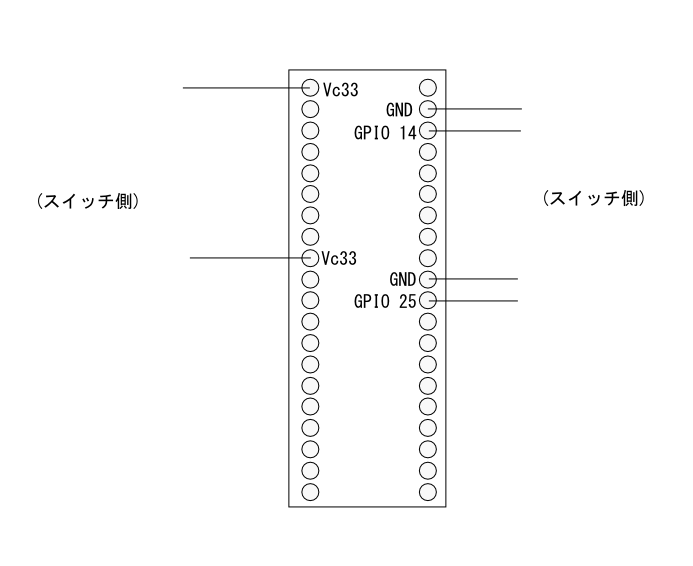
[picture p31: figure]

図 2 Raspberry Pi GPIO 図

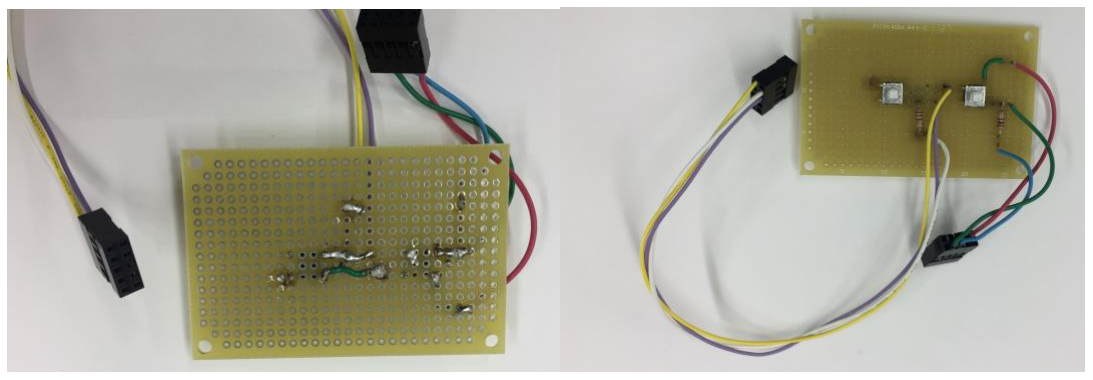
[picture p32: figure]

図３作成例

2. シェルスクリプトの作成
起動時に自動でコンポーネントを起動し、アクティブするためのシェルスクリプトを Raspberry Pi に保存する。
ここでは Zumo-comp.py と LineTracer-comp.py で説明する。

2.1 RTShell のインストール
コンポーネントをスイッチ一つで起動するために RTShell をインストールする。 RTShell は pip でインストールできる。

$sudo pip install rtshell

インストール後、次のコマンドをうち、適宜 y を入力する。

$rtshell_post_install

なお、このままでは rtcon コマンドを使用する際、

‘module’ object has no attribute ‘any’

というエラーが出力されるため、

/usr/local/lib/python2.7/dist-packages/rtctree

に存在する「utils.py」の「import omniORB」という 1 文を次のものに置き換える

Import omniORB.any

2.2 スクリプトの設定
2.2.1 python スクリプトの作成
RTShell を使用し、コンポーネントを立ち上げ、接続、アクティブにするためのプログ ラム ActiveComp.py を GitHub の Scripts ファイルから/home/pi/に保存する。 次に、コンポーネントを停止させ、exit させるためのプログラム DeactiveComp.py を GitHub の Scripts ファイルから/home/pi/に保存する。

2.2.2 シェルスクリプトの登録
起動時に立ち上げるため/etc/rc.local に以下の 2 文を書き込む。このとき exit 0 の上 に書き、&を忘れないこと。

sh runZumo.sh &
sh stopZumo.sh &

runZumo.sh の内容は以下の通りで/etc/に置く。

#!/bin/sh

sudo python ActiveComp.py &

stopZumo.sh の内容は以下の通りで/etc/に置く。

#!/bin/sh

Sudo python DeactiveComp.py &

runZumo.sh と stopZumo.sh に実行権限を付与する。 $ sudo chmod 755 /etc/runZumo.sh
$ sudo chmod 755 /etc/stopZumo.py

これで再起動すると自動で ActiveComp.py と DeactiveComp.py が起動するようになる。

3．更新情報
2016 年 12 月 12 日 初版

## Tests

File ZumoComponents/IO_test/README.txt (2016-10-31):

README

甲南大学知能情報学部
2016/10/31

このフォルダには，RTミドルウェアコンテスト2016に参加している「ZumoとRaspberry Piを用いた教育用ロボット環境」のPololu Zumoロボット 制御I/Oテスト用RTコンポーネントが保存されています．

このフォルダには，本コンポーネント群を動作させるための制御用I/Oの動作を確認するための以下のファイルから構成されています．

(1) Zumoロボットの赤外線センサアレイの出力を確認するためのRTコンポーネント

これらのコンポーネントはPythonで書かれており，Raspberry Pi，Windows などプラットフォームを問わず，実行できます．これらのデータは以下のファイル名で保存されています．

- ULongSeqInput.py	符号なしLong型配列(TimedULongSeq)の入力・端末への出力コンポーネント
			Zumoロボットの赤外線センサアレイの出力を確認するために用います．
 
これらのRTコンポーネント群を用いてZumoロボットのセンサの出力を確認する方法については，本プロジェクトのマニュアルを参照してください．

以上

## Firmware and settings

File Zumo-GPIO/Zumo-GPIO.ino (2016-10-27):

#include <Zumo32U4.h>

#include "Motor.h"
#include "SerialPort.h"
#include "Button.h"
#include "LineSensor.h"

Motor motor;
SerialPort Port;
Button button;
LineSensor lsens;
void setup() {
  // put your setup code here, to run once:

}
void loop() {
  static unsigned long LastTime = 0;
  static unsigned long WaitTime = 20; //[ms]
  static bool SendData = true;
  // put your main code here, to run repeatedly:

  /*データの受信*/
  while (true) {
    switch (Port.CheckData()) {
      case 0x00:
        break;
      //0x01
      case 0x02:
        motor.SetSpeedL(Port.GetFloat());
        break;
      case 0x03:
        motor.SetSpeedR(Port.GetFloat());
        break;
      case 0x04:
        ledRed(Port.GetBool());
        break;
      case 0x05:
        ledGreen(Port.GetBool());
        break;
      case 0x06:
        ledYellow(Port.GetBool());
        break;
      //0x07 ... 0x73
      case 0x74:
        motor.SetKP(Port.GetFloat());
        break;
      case 0x75:
        motor.SetKI(Port.GetFloat());
        break;
      case 0x76:
        motor.SetKD(Port.GetFloat());
        break;
      //0x77
      case 0x78:
        SendData = Port.GetBool();
        break;
      case 0x79:
        WaitTime = Port.GetULong();
        break;
      //0x7A .. 0x7F
      default:
        /*受信したデータが無い or 受信に失敗したため、ループを脱出*/
        goto ExitLoop;
    }
  }
ExitLoop:
  /*データの送信*/
  if (millis() - LastTime >= WaitTime) {
    LastTime = millis();

    motor.SetSpeed();

    if (SendData) {
      motor.SendSpeed(Port);
      lsens.SendStatus(Port);
    }
  }
  /*ボダンの情報送信*/
  button.SendStatus(Port);
}

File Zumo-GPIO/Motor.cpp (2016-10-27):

#include "Motor.h"

/*コンストラクタ*/
Motor::Motor() {
  VL = 0;
  VR = 0;
  KP = 0.1;
  KI = 0.2;
  KD = 0.05;
  sL = 0;
  sR = 0;
  pL = 0;
  pR = 0;
  LastT = 0;
}

/**
   クローラの現在の速度を送信
   引数   : port : シリアルポートインスタンス
   返り値 : 無し
*/
void Motor::SendSpeed(SerialPort port) {
  port.Send(0x02, RL);
  port.Send(0x03, RR);
}

/**
   設定された速度になるようモータを制御
   引数   : 無し
   返り値 : 無し
*/
void Motor::SetSpeed() {
  /*現在のエンコーダの値*/
  int16_t Lc = enc.getCountsAndResetLeft();
  int16_t Rc = enc.getCountsAndResetRight();
  /*現在の時刻*/
  unsigned long T = micros(); //[us]
  /*前回制御時からの時間差*/
  long dT;//[us]
  if (T > LastT) {
    dT = T - LastT;
  } else {
    dT = T + (~LastT);
    /* ULMaxをunsigned longの最大値とする

      T - (LastT - ULMax)
      = ULMax + T - LastT
      = ULMax + T + (-LastT)
      = ULMax + T + (~LastT + 1)
      = ULMax + T + ~LastT + 1
      = ULMax + 1 + T + ~LastT
      = 0 + T + ~LastT
      (なぜなら、符号なし整数の最大値はすべてのビットが"1"で、
      そこに1を加算するとオーバーフローして0になるから）
      = T + ~LastT
    */
  }
  /*現在の実速度の設定*/
  RL = Lc * (float)US_S / dT;// Lc/(dT/US_S)
  RR = Rc * (float)US_S / dT;// Rc/(dT/US_S)
  /*目標速度との差*/
  float L = VL - RL;
  float R = VR - RR;
  /*前回の目標速度との差との差*/
  float dL = L - pL;
  float dR = R - pR;
  /*目標速度との差の累計*/
  sL += L;
  sR += R;
  /*制御地の設定及び送信*/
  float LP = KP * L + KI * sL + KD * dL;
  float RP = KP * R + KI * sR + KD * dR;
  mtr.setSpeeds(MTR_VAL(LP), MTR_VAL(RP));

  pL = L; pR = R; LastT = T;
}

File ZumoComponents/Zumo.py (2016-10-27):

#!/usr/bin/env python
# -*- coding: utf-8 -*-
# -*- Python -*-

"""
 \file Zumo.py
 \brief ModuleDescription
 \date $Date$


"""
import sys
import time
sys.path.append(".")

# Import RTM module
import RTC
import OpenRTM_aist
import serial
import struct
import threading
from collections import defaultdict
import math

# Import Service implementation class
# <rtc-template block="service_impl">

# </rtc-template>

# 参考 http://www.mech.tohoku-gakuin.ac.jp/rde/contents/course/robotics/wheelrobot.html
 #転輪幅(メートル)
tread=85*0.001
# ギア比 75.81:1
# モータのシャフト1回転あたりのカウント数 12
# 転輪直径(クローラ込み) 40mm
# 1ポイントあたりの移動距離(メートル)と、逆数
MPCnt=(40*0.001*math.pi)/(75.81*12)#[m/Pt]
CntPM=(75.81*12)/(40*0.001*math.pi)#[Pt/m]
# シリアル通信のタイムアウト
TimeOut=1.0
# 転輪幅の半分
hftr=tread/2
Epsilon=10**(-10)
#ラインセンサの数
LSensCount=5

class Bool4:
    # ブール値を4バイト整数に変換
    # struct.Structの代わりに使用
    @staticmethod
    def pack(v):
        if v:
            return "\x01\x00\x00\x00"
        return "\x00\x00\x00\x00"
    @staticmethod
    def unpack(v):
        if v=="\x00\x00\x00\x00":
            return (False,)
        return (True,)
U_Int=struct.Struct("<L")       # 符号なし整数(4バイト)
S_Int=struct.Struct("<l")       # 符号付き整数(4バイト)
Float=struct.Struct("<f")       # 浮動小数(単精度)
DataS=struct.Struct("BBBBBB")   # 6バイト値
DataM=struct.Struct("B")        # 1バイト値

# シリアライズ用テーブル
# Zumoへ値を送信する時に使用
SendDict=defaultdict(lambda:U_Int,
    {
        0x02:Float,0x03:Float,
        0x04:Bool4,0x05:Bool4,0x06:Bool4,
        0x74:Float,0x75:Float,0x76:Float,
        0x78:Bool4,0x79:U_Int,
    })
# デシリアライズ用テーブル
# Zumoから値が送信された時に使用
ResvDict=defaultdict(lambda:U_Int,
    {
        0x02:Float,0x03:Float,
        0x08:Bool4,0x09:Bool4,0x0A:Bool4,
        0x10:U_Int,0x11:U_Int,0x12:U_Int,0x13:U_Int,0x14:U_Int
    })

CRC_Base=0b1011L
def CalcCRC(data):# CRC値の計算
    CRCV = CRC_Base<<35
    CRCM = 1L<<38
    for i in range(36):
        if data & CRCM:
            data^=CRCV
        CRCV>>=1
        CRCM>>=1
    return data&0x7

def MakeData(ID,Data):# データのシリアライス
    Conv =SendDict[ID]
    Data =U_Int.unpack(Conv.pack(Data))[0]
    Data|=long(ID)<<32
    CRC  =CalcCRC(Data)
    Data =(Data<<3) | CRC
    RetL =[0,0,0,0,0,0x80]
    for i in range(6):
        Sh=7*(5-i)
        Dp=(Data&(0x7f<<Sh))>>Sh
        RetL[i]|=Dp
    return DataS.pack(*RetL)

def DecodeData(Data):# データのデシリアライス
    if len(Data)<6:
        return None,"Too Short"
    DataL=0
    for i in Data:
        DataL=(DataL<<7)|(i&0x7F)
    DataL&=0x3FFFFFFFFFF
    ID  = DataL>>35
    Data=(DataL>>3 )&0xFFFFFFFF
    CRC = DataL     &0x7
    CRCt=CalcCRC(DataL>>3)
    if CRC==CRCt:
        Conv =ResvDict[ID]
        return ID,Conv.unpack(U_Int.pack(Data))[0]
    return None,"CRC ERROR {0} {1}".format(CRC,CRCt)

#何もしない関数
NoFunc=lambda x:None

# Import Service stub modules
# <rtc-template block="consumer_import">
# </rtc-template>


# This module's spesification
# <rtc-template block="module_spec">
zumo_spec = ["implementation_id", "Zumo",
		 "type_name",         "Zumo",
		 "description",       "ModuleDescription",
		 "version",           "1.0.0",
		 "vendor",            "VenderName",
		 "category",          "Category",
		 "activity_type",     "STATIC",
		 "max_instance",      "1",
		 "language",          "Python",
		 "lang_type",         "SCRIPT",
		 "conf.default.Port", "COM1",
		 "conf.__widget__.Port", "text",
		 ""]
# </rtc-template>

class Zumo(OpenRTM_aist.DataFlowComponentBase):

	"""
	\class Zumo
	\brief ModuleDescription

	"""
	def __init__(self, manager):
		"""
		\brief constructor
		\param manager Maneger Object
		"""
		OpenRTM_aist.DataFlowComponentBase.__init__(self, manager)

		self._d_VelocityIn = RTC.TimedVelocity2D(RTC.Time(0,0),0)
		"""
		"""
		self._VelocityInIn = OpenRTM_aist.InPort("VelocityIn", self._d_VelocityIn)
		self._d_VelocityOut = RTC.TimedVelocity2D(RTC.Time(0,0),0)
		"""
		"""
		self._VelocityOutOut = OpenRTM_aist.OutPort("VelocityOut", self._d_VelocityOut)
		self._d_PoseOut = RTC.TimedPose2D(RTC.Time(0,0),0)
		"""
		"""
		self._PoseOutOut = OpenRTM_aist.OutPort("PoseOut", self._d_PoseOut)
		self._d_ButtonA = RTC.TimedBoolean(RTC.Time(0,0),0)
		"""
		"""
		self._ButtonAOut = OpenRTM_aist.OutPort("ButtonA", self._d_ButtonA)
		self._d_ButtonB = RTC.TimedBoolean(RTC.Time(0,0),0)
		"""
		"""
		self._ButtonBOut = OpenRTM_aist.OutPort("ButtonB", self._d_ButtonB)
		self._d_ButtonC = RTC.TimedBoolean(RTC.Time(0,0),0)
		"""
		"""
		self._ButtonCOut = OpenRTM_aist.OutPort("ButtonC", self._d_ButtonC)
		self._d_LineSensors = RTC.TimedULongSeq(RTC.Time(0,0),0)
		"""
		"""
		self._LineSensorsOut = OpenRTM_aist.OutPort("LineSensors", self._d_LineSensors)





		# initialize of configuration-data.
		# <rtc-template block="init_conf_param">
		"""

		 - Name:  Port
		 - DefaultValue: COM1
		"""
		self._Port = ['COM1']

		# </rtc-template>
		# シリアルポート
		self.SPort=None
		# 最後に計算したX座標,Y座標,角度,時間
		self.X=0
		self.Y=0
		self.A=0
		self.T=0
		# 受信データ
		self.Received=[]
		# 受信データに対するアクション用関数テーブル
		# 引数は1つ(受信したデータ・型はResvDictに依存)
		self.Functions=defaultdict(lambda:NoFunc,
                        {
                                0x02:self.SetLeft,
                                0x03:self.SetRight,

                                0x08:self.ButtonA,
                                0x09:self.ButtonB,
                                0x0A:self.ButtonC,

                                0x10:self.LineSensor0,
                                0x11:self.LineSensor1,
                                0x12:self.LineSensor2,
                                0x13:self.LineSensor3,
                                0x14:self.LineSensor4,
                        })
		self._LSens=[0]*LSensCount


	def SetLeft(self,Data):# 左クローラ速度の受信・保持
		self.VLr=Data*MPCnt
	def SetRight(self,Data):# 右クローラ速度の受信・保持
		self.VRr=Data*MPCnt
	def ButtonA(self,stat):
		self._d_ButtonA.data=stat
		OpenRTM_aist.setTimestamp(self._d_ButtonA)
		self._ButtonAOut.write()
	def ButtonB(self,stat):
		self._d_ButtonB.data=stat
		OpenRTM_aist.setTimestamp(self._d_ButtonB)
		self._ButtonBOut.write()
	def ButtonC(self,stat):
		self._d_ButtonC.data=stat
		OpenRTM_aist.setTimestamp(self._d_ButtonC)
		self._ButtonCOut.write()
	def LineSensor0(self,value):
		self._LSens[0]=value
	def LineSensor1(self,value):
		self._LSens[1]=value
	def LineSensor2(self,value):
		self._LSens[2]=value
	def LineSensor3(self,value):
		self._LSens[3]=value
	def LineSensor4(self,value):
		self._LSens[4]=value

	def onInitialize(self):
		"""

		The initialize action (on CREATED->ALIVE transition)
		formaer rtc_init_entry()

		\return RTC::ReturnCode_t

		"""
		# Bind variables and configuration variable
		self.bindParameter("Port", self._Port, "COM1")

		# Set InPort buffers
		self.addInPort("VelocityIn",self._VelocityInIn)
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

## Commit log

2016-10-27 Revert "GamePad-component"
    This reverts commit 38d07c1322952e2b7f0a4ff633abf123423021ca.
    [signal.ods]
2016-10-28 Zumoの初期設定
2016-10-28 治具CADデータ
    Zumoの基板上にRaspberry Pi A+を載せるための治具のCADデータおよび3Dプリンタ用データです．3DプリンタデータはAfinia
    H480用のものです(拡張子は.UP3)．
2016-10-28 Revert "治具CADデータ"
    This reverts commit d25909e616428ac6014fad0819fe98b0be3bca50.
2016-10-28 CADデータ
    Zumoの基板上にRaspberry Pi A+を載せるための治具のCADデータおよび3Dプリンタ用データ
2016-10-31 RTCs for Pololu Zumo 32U4
    [signal.ods]
2016-12-07 Revert "CADdata1207"
    This reverts commit 64617a1daec7e1d3676b08f594d72f335a161e76.
    [JigA-1.stl, JigA-2.stl, JigA-3.stl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]
